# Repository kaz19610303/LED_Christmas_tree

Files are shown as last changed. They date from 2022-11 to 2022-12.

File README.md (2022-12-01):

# LED_Christmas_tree DIY kit



3mm LED 36個と5mm LED1個を使った、LEDクリスマスツリー DIY キットです。  
ご自身でハンダ付けする必要があります。  
  
回路図と基板データを登録していますのでそれを基にオリジナルのクリスマスツリーをお作り下さい。  
現在 Eagle用のデータのみ登録
KiKADデータは準備中 
ドキュメントページはただ今準備中です。

このDIYキットはこちらのページで販売予定です。
https://nextstep.official.ec/  
  
この基板の作成には [JLCPCB](https://jlcpcb.com/HAR) 様の支援を受けています。  
なお現在 JLCPCB は**新規登録で$54クーポン進呈キャンペーン継続中**です。

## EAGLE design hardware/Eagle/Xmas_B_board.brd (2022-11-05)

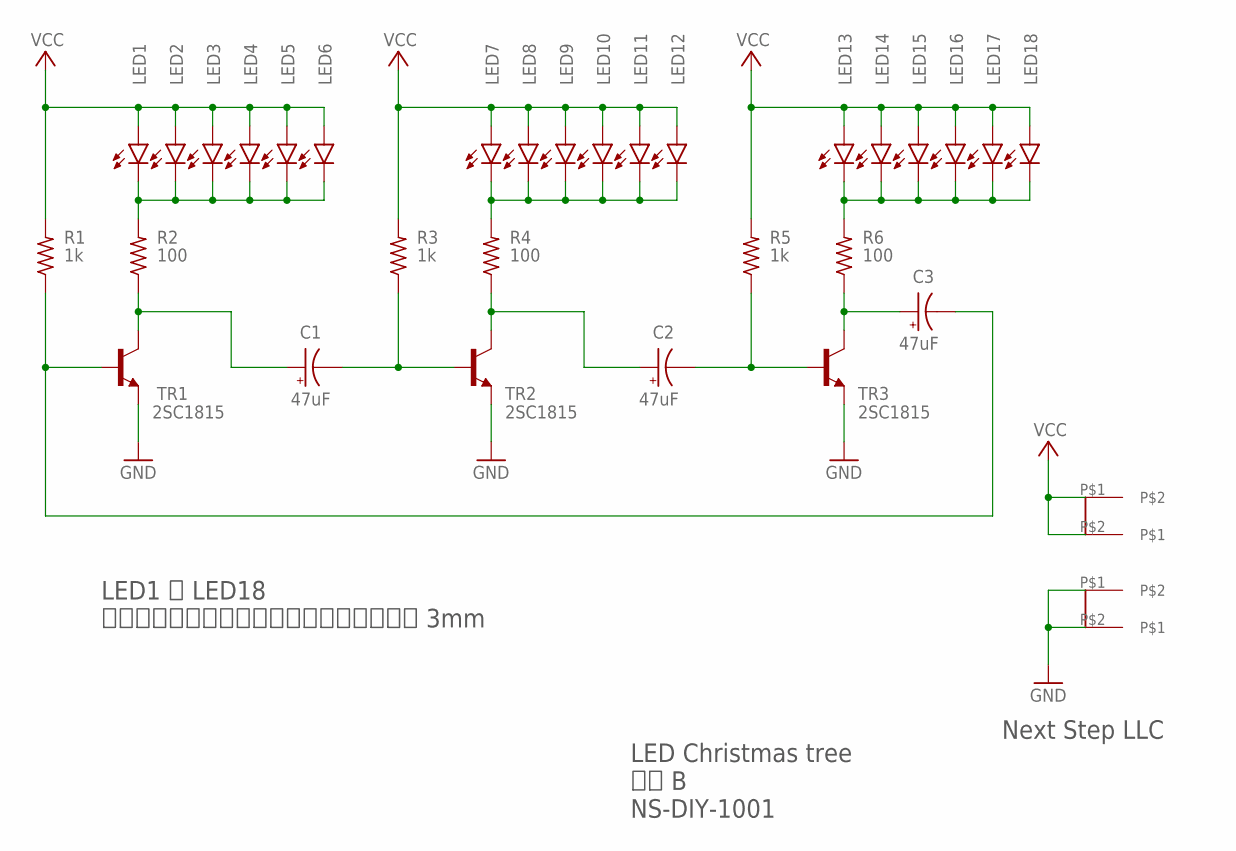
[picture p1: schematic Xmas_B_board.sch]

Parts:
C1, C2, C3: 47uF; E2-4
LED1, LED2, LED3, LED4, LED5, LED6, LED7, LED8, LED9, LED10, LED11, LED12, LED13, LED14, LED15, LED16, LED17, LED18: LED3MM
R1, R3, R5: 1k; 0204/7
R2, R4, R6: 100; 0204/7
TR1, TR2, TR3: 2SC1815; TO92-ECB
U$1, U$2: XMAS_POWER

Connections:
GND: TR1.E, TR2.E, TR3.E, U$2.P$1, U$2.P$2
unnamed: C3.-, R1.1, TR1.B
unnamed: LED1.K (C), LED2.K (C), LED3.K (C), LED4.K (C), LED5.K (C), LED6.K (C), R2.2
unnamed: C1.+, R2.1, TR1.C
unnamed: LED7.K (C), LED8.K (C), LED9.K (C), LED10.K (C), LED11.K (C), LED12.K (C), R4.2
unnamed: C2.+, R4.1, TR2.C
unnamed: C1.-, R3.1, TR2.B
unnamed: C3.+, R6.1, TR3.C
unnamed: C2.-, R5.1, TR3.B
unnamed: LED13.K (C), LED14.K (C), LED15.K (C), LED16.K (C), LED17.K (C), LED18.K (C), R6.2
VCC: LED1.A, LED2.A, LED3.A, LED4.A, LED5.A, LED6.A, LED7.A, LED8.A, LED9.A, LED10.A, LED11.A, LED12.A, LED13.A, LED14.A, LED15.A, LED16.A, LED17.A, LED18.A, R1.2, R3.2, R5.2, U$1.P$1, U$1.P$2

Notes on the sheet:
LED1 ～ LED18 ＲＧＢイルミネーションフルカラーＬＥＤ 3mm
LED Christmas tree 基板 B NS-DIY-1001
Next Step LLC

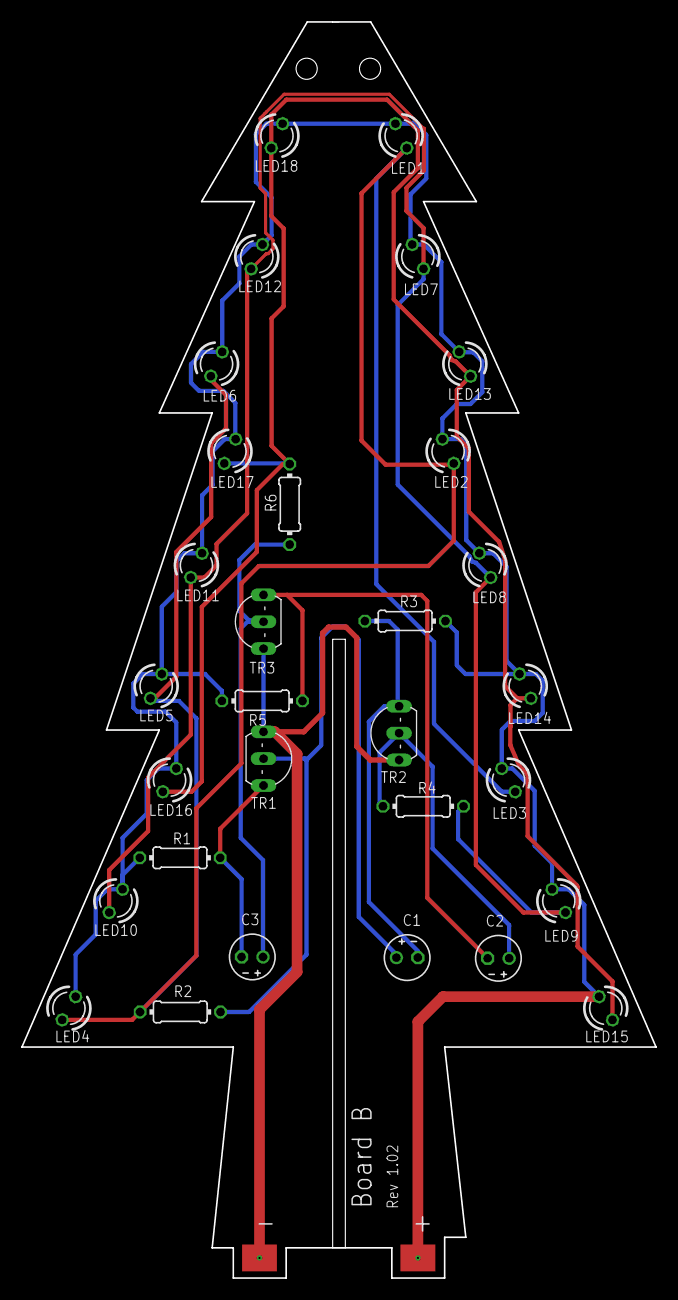
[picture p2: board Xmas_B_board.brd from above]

Board: 2 copper layers, 60.0 x 118.9 mm, 32 parts (0 on the bottom side), 11 nets.

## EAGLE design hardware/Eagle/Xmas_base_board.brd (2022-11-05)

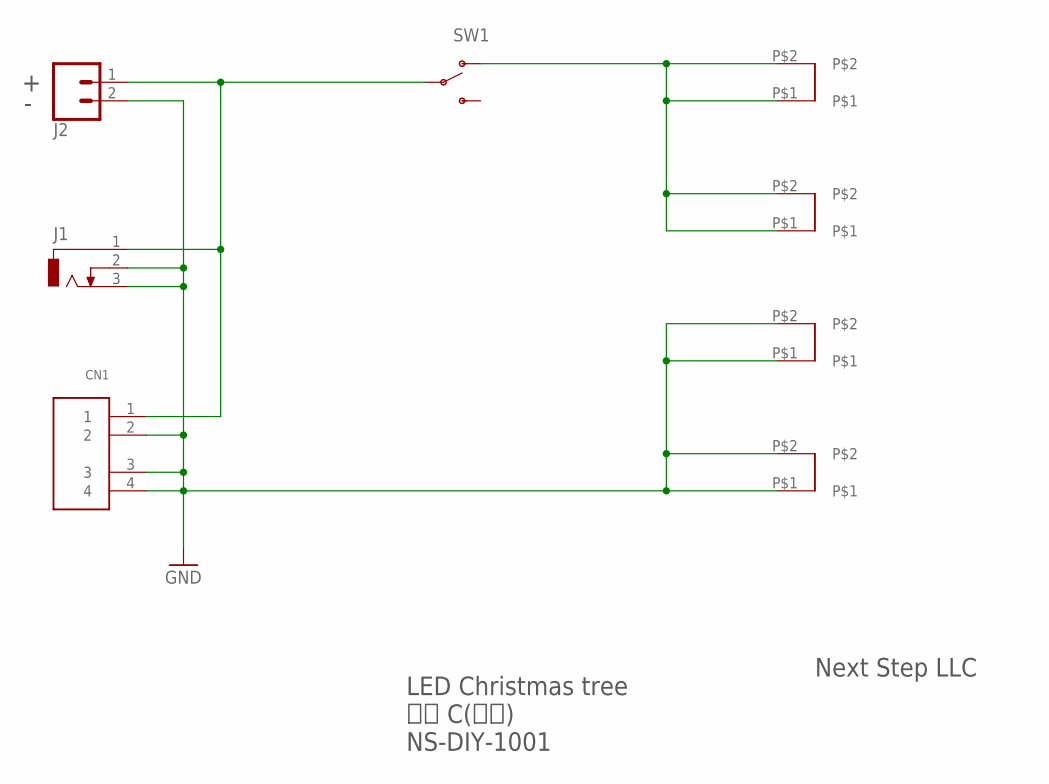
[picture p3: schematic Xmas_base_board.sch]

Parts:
CN1: MRUSB-2B-D14NI-S306_MRUSB-2B
J1: DCJ0303
J2: CONN_02; 1X02
SW1: SWITCH-SPDT-PTH-11.6X4.0MM; SWITCH_SPDT_PTH_11.6X4.0MM
U$5, U$6, U$7, U$8: XMAS-TREE

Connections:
GND: CN1.2, CN1.3, CN1.4, J1.2, J1.3, J2.2, U$7.P$1, U$7.P$2, U$8.P$1, U$8.P$2
unnamed: CN1.1, J1.1, J2.1, SW1.2
unnamed: SW1.1 (O), U$5.P$1, U$5.P$2, U$6.P$1, U$6.P$2

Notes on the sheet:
LED Christmas tree 基板 C(台座) NS-DIY-1001
Next Step LLC

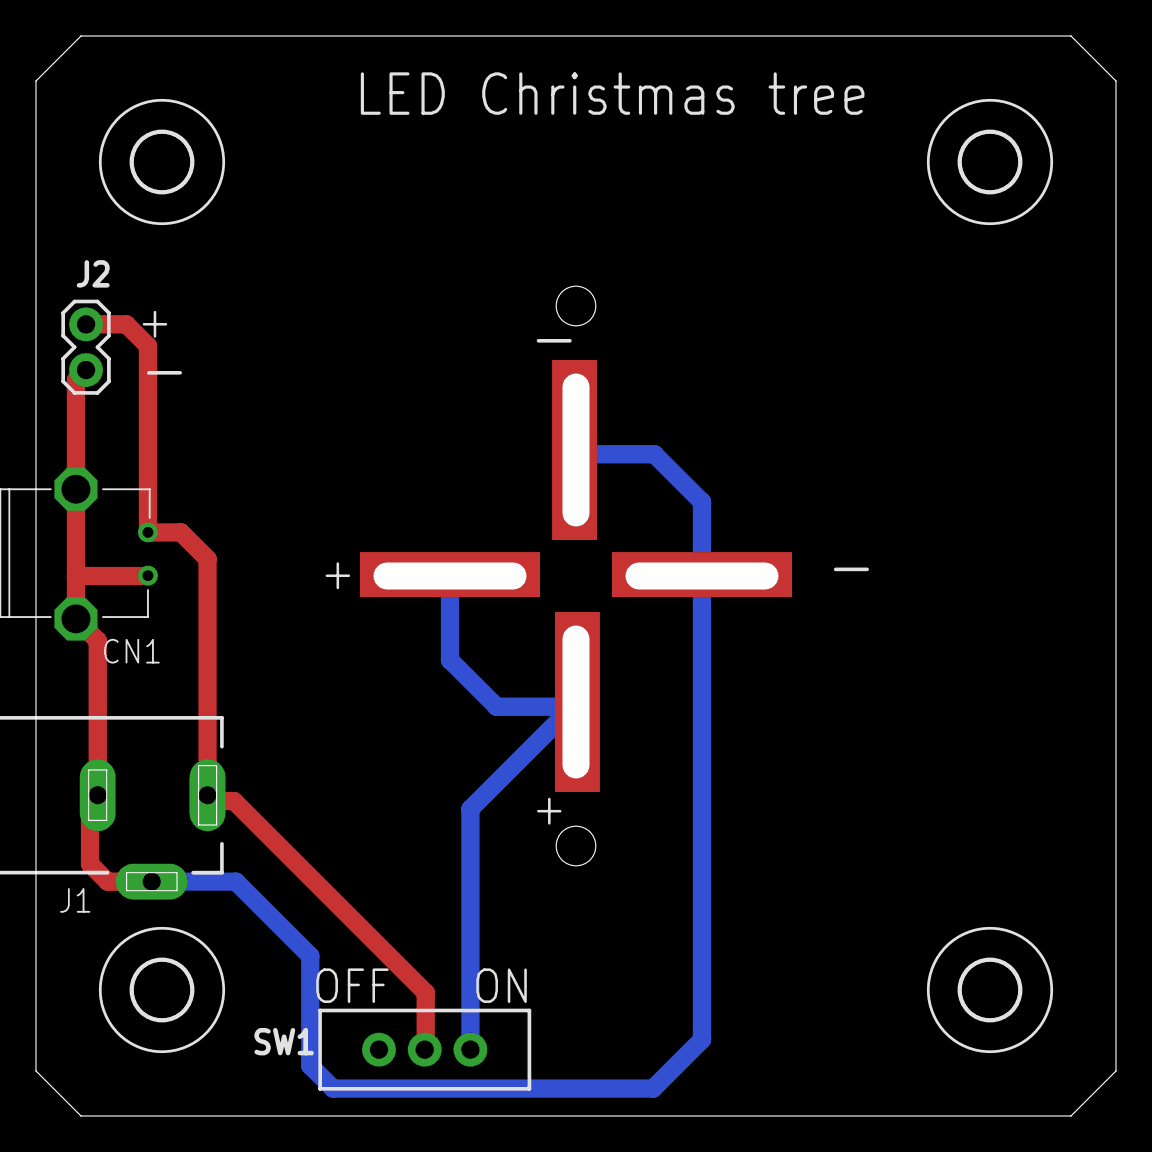
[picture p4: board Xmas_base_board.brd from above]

Board: 2 copper layers, 60.0 x 60.0 mm, 12 parts (0 on the bottom side), 3 nets.

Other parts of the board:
U$1, U$2, U$3, U$4: 3,2

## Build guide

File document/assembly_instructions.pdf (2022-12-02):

# LEDクリスマスツリー組立説明書

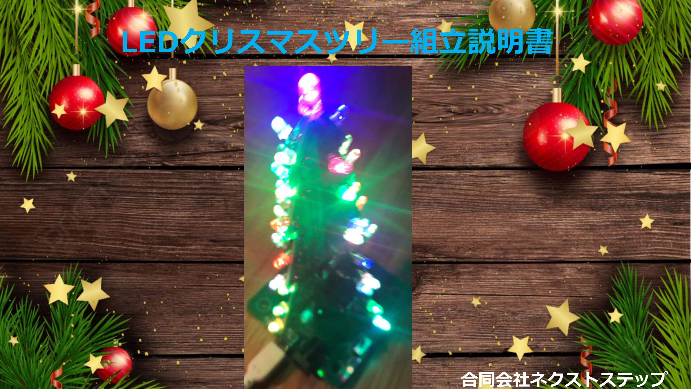
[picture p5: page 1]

# 合同会社ネクストステップ

# 部品表

LEDクリスマスツリー DIY キット A基板 部品表

取付順 | 部品番号 | 品名 | 数量 | 備考
1R2, R4, R6 | | 抵抗 100Ω | 3茶 黒 茶
2R1, R3, R5 | | 抵抗 1kΩ | 3茶 黒 赤
3R7 | | 抵抗 330Ω | 1橙 橙 茶
4LED1 ～ LED18 | | LED 3mm | 18極性あり 足が長い方が ＋
5TR1, TR2, TR3 | | トランジスタ 2SC1815 | 3極性あり 基板の印刷に合わせる、TR2は横に曲げる
6C1, C2, C3 | | 電界コンデンサ 47uF | 3極性あり 足が長い方が ＋
7LED19 | | LED 5mm | 1極性あり 足が長い方が ＋、3枚の基板を組み合わせた後に付ける
| | 基板 | 1

LEDクリスマスツリー DIY キット B基板 部品表

取付順 | 部品番号 | 品名 | 数量 | 備考
1R2, R4, R6 | | 抵抗 100Ω | 3茶 黒 茶
2R1, R3, R5 | | 抵抗 1kΩ | 3茶 黒 赤
3LED1 ～ LED18 | | LED 3mm | 1極性あり 足が長い方が ＋
4TR1, TR2, TR3 | | トランジスタ 2SC1815 | 3極性あり 基板の印刷に合わせる
5C1, C2, C3 | | 電界コンデンサ 47uF | 3極性あり 足が長い方が ＋、そあは下に曲げる
| | 基板 | 1

LEDクリスマスツリー DIY キット ベースボード 部品表

取付順 | 部品番号 | 品名 | 数量 | 備考
1 | | マイクロB | 1
2 | | スライドSW | 1
3 | | DCジャック | 1
| | 基板 | 1
| | 20mmスペーサー | 4
| | 3mmビス | 4

# 組み立てを始める前に 部品が揃っているか確認します

# セット内容

# ① 基板

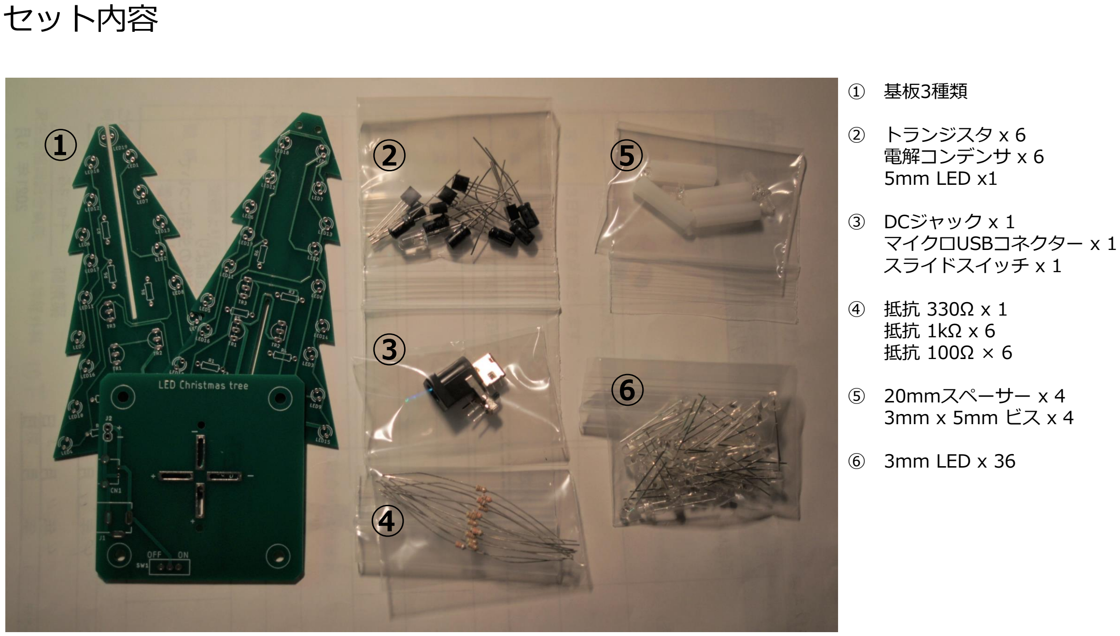
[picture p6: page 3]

3種類

# ② トランジスタ x 6 電解コンデンサ x 6 5mm LED x1

# ③ DCジャック x 1 マイクロUSBコネクター x 1 スライドスイッチ x 1

# ④ 抵抗 330Ω x 1 抵抗 1kΩ x 6 抵抗 100Ω

×

6

# ⑤ 20mmスペーサー x 4 3mm x 5mm ビス x 4

# ⑥ 3mm LED x 36

①

# ②③④

⑤⑥

# A基板回路図

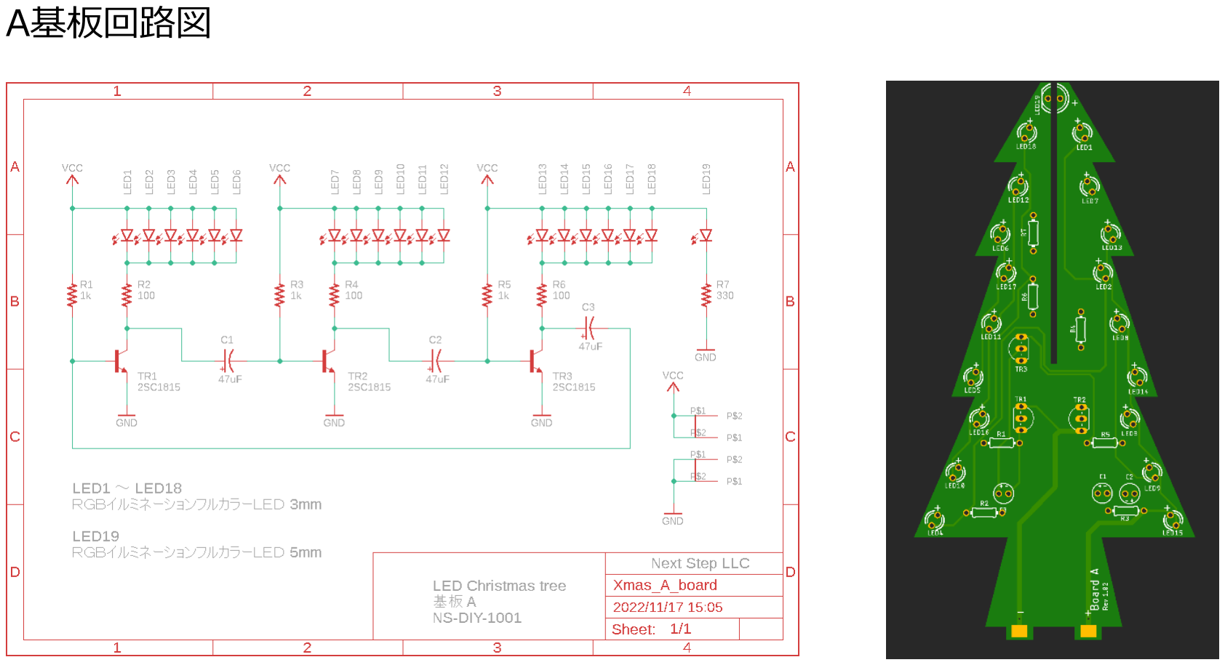
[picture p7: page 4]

# B基板回路図

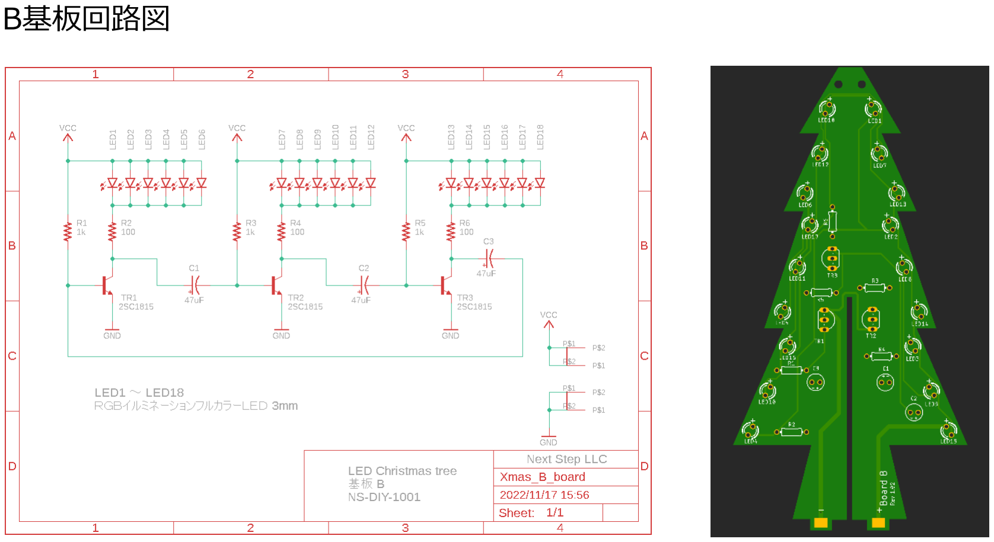
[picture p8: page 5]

# ベース基板回路図

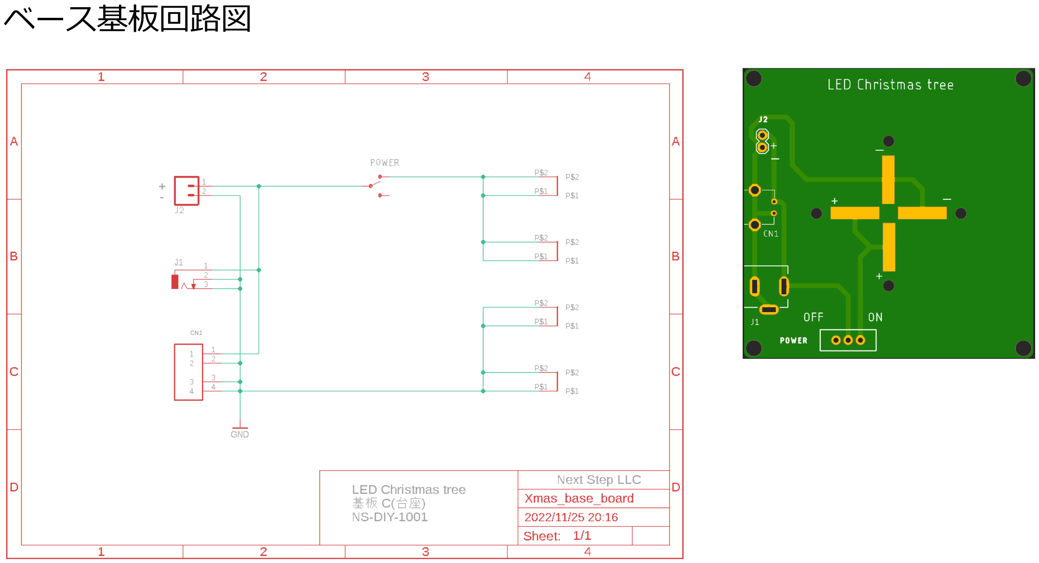
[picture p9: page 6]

# プリント基板

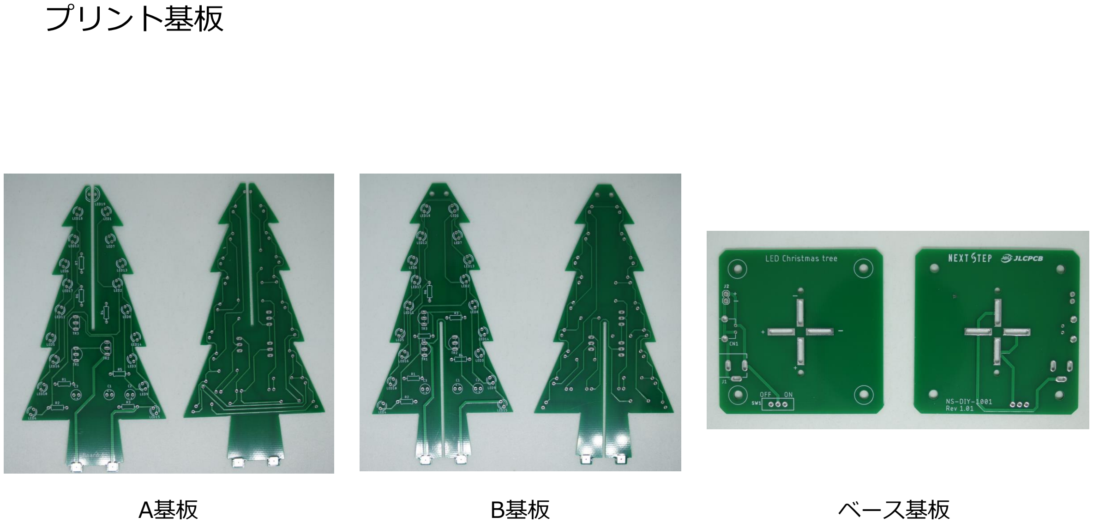
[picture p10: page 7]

A基板 | B基板 | ベース基板

# A基板・B基板の組み立て

① | ② | ③

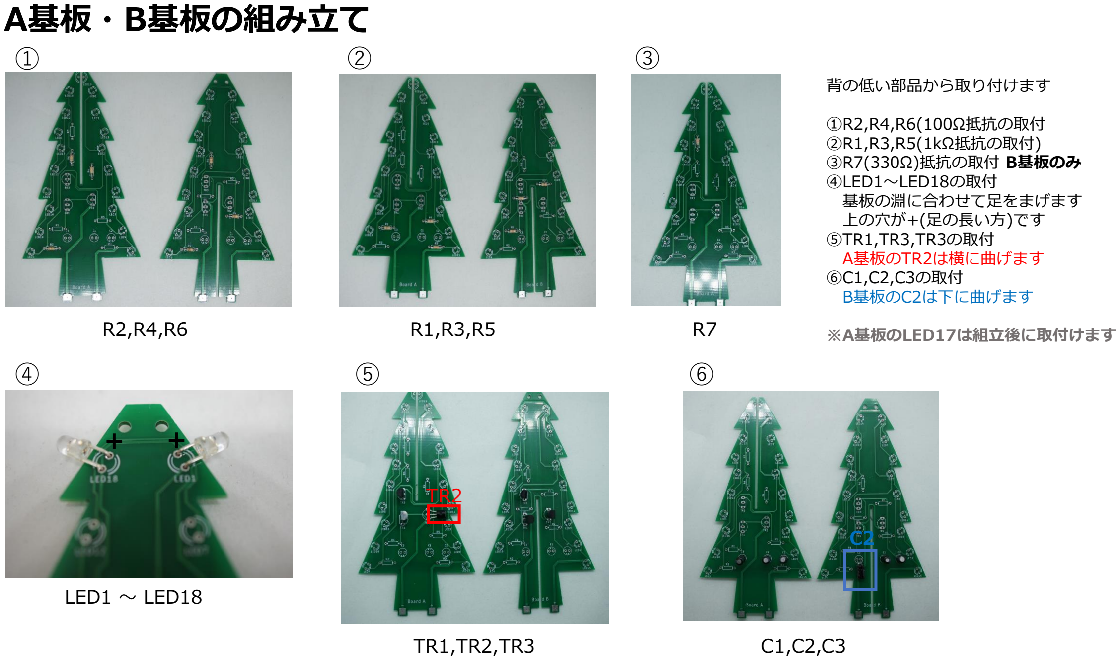
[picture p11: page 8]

R2,R4,R6 | R1,R3,R5 | R7
TR1,TR2,TR3 | C1,C2,C3
④ | ⑤ | ⑥

# LED1 ～ LED18

＋ ＋

# 背の低い部品から取り付けます

# ①R2,R4,R6(100Ω抵抗の取付 ②R1,R3,R5(1kΩ抵抗の取付) ③R7(330Ω)抵抗の取付 B基板のみ ④LED1～LED18の取付 基板の淵に合わせて足をまげます 上の穴が+(足の長い方)です ⑤TR1,TR3,TR3の取付 A基板のTR2は横に曲げます ⑥C1,C2,C3の取付 B基板のC2は下に曲げます

# ※A基板のLED17は組立後に取付けます

TR2

C2

# ベース基板の組み立て

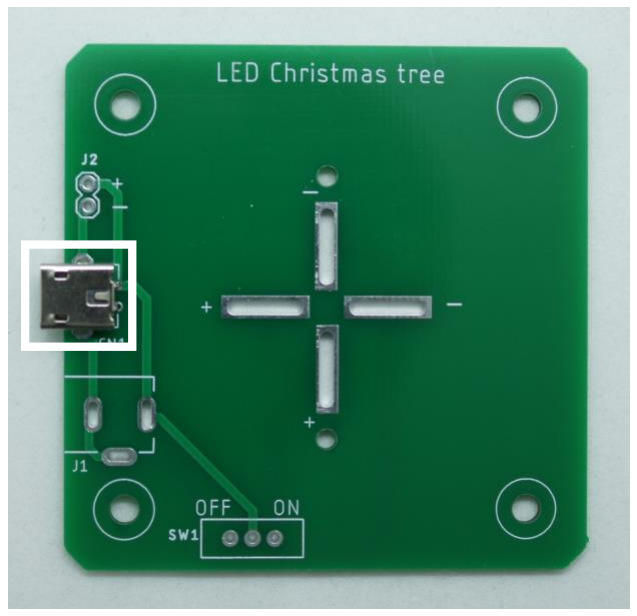
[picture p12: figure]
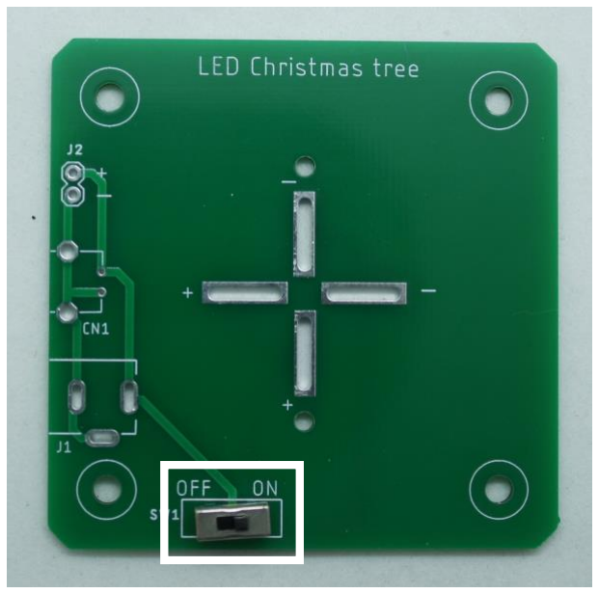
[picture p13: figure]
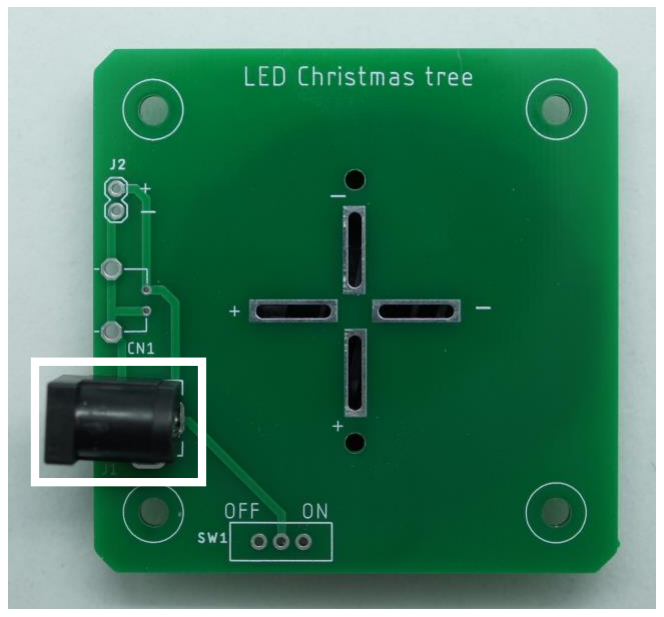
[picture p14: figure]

1. | マイクロUSBコネクター | 2. スライドスイッチ | 3. DCジャック

# ベース基板も背の低い部品からハンダ付けします

# 各基板の組み合わせ

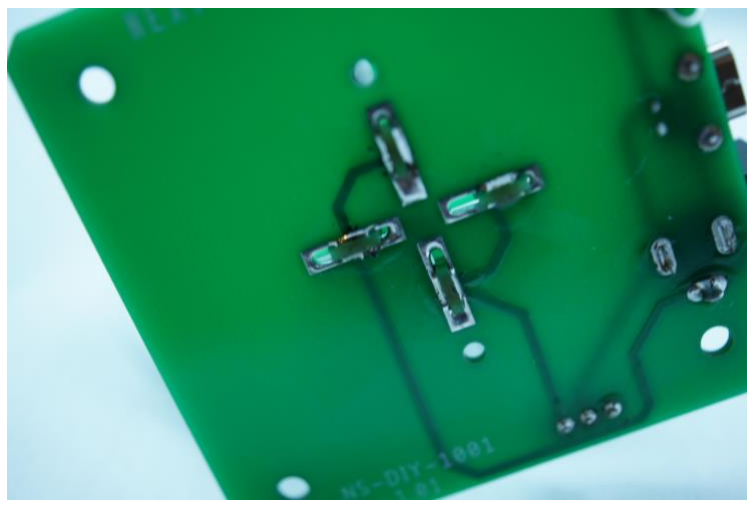
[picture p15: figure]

# A基板・B基板をベース基板にハンダ付けします

# A基板・B基板とベース基板の +と⁻を間違わないようにしてください

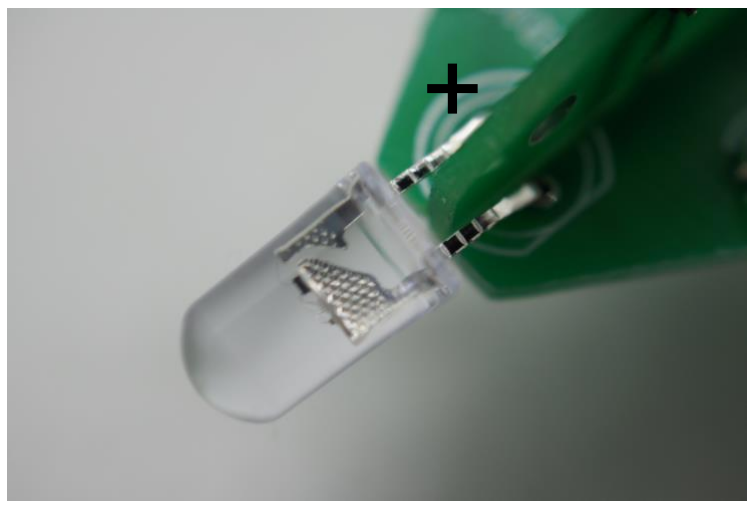
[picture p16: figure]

# LED17の取付

# このLEDも基板の淵に合わせて曲げます 向かって右側が + です

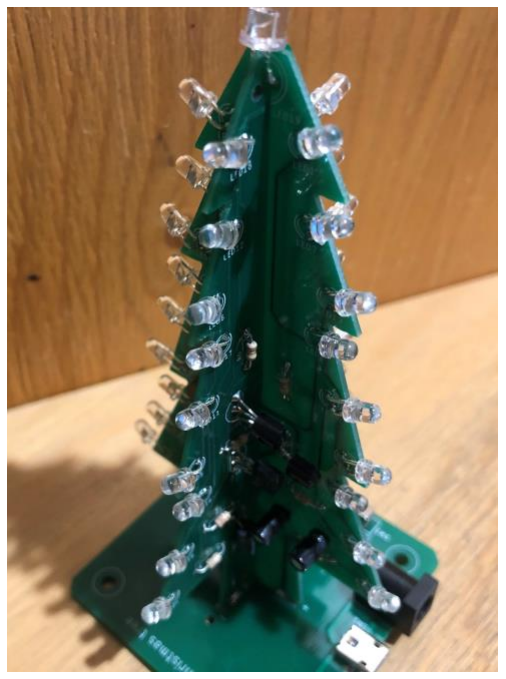
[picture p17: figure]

# A基板・B基板は溝を合わせて組付けます

# 動作確認

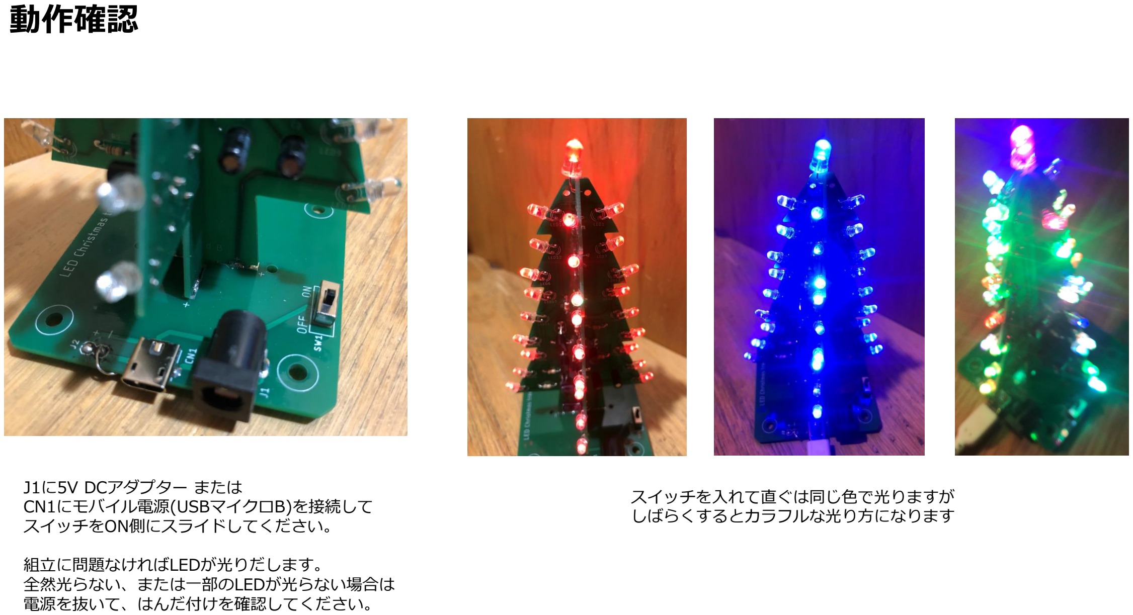
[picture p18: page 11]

# J1に5V DCアダプター または CN1にモバイル電源(USBマイクロB)を接続して スイッチをON側にスライドしてください。

# 組立に問題なければLEDが光りだします。 全然光らない、または一部のLEDが光らない場合は 電源を抜いて、はんだ付けを確認してください。

# スイッチを入れて直ぐは同じ色で光りますが しばらくするとカラフルな光り方になります

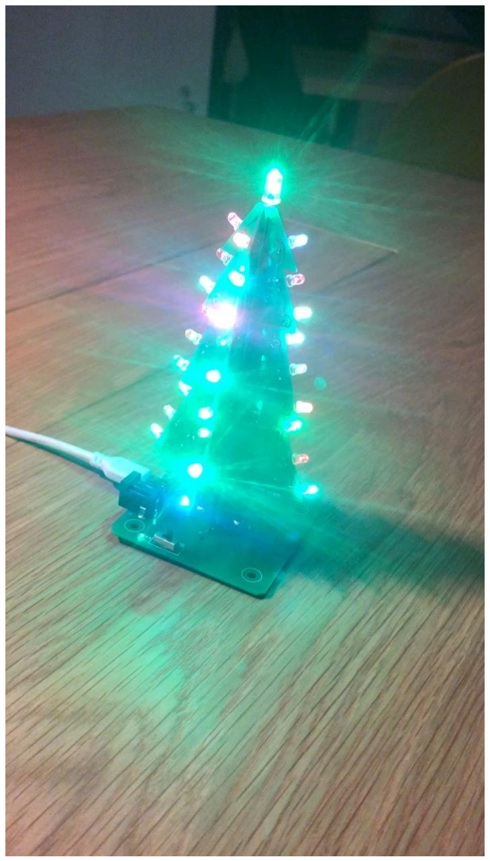
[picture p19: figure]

# 完成したLED クリスマスツリー

# 合同会社 ネクストステップ 問合せ info@next-step.asia

# 販売サイト https://nextstep.official.ec/

# ドキュメントダウンロード GitHUB https://github.com/kaz19610303/LED_Christmas_tree

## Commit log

2022-11-03 Eagle data upload
    [Xmas_A_board.brd, Xmas_A_board.sch, Xmas_B_board.brd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]
2022-11-05 garber data upload
    [Xmas_A_board.brd, Xmas_B_board.brd, Xmas_base_board.brd]
2022-11-05 抵抗の定数変更
    [Xmas_A_board.brd, Xmas_A_board.sch, Xmas_B_board.brd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]
2022-12-01 assembly_instructions 追加
2022-12-01 assembly_instructions upload
2022-12-02 assembly_instructions 加筆

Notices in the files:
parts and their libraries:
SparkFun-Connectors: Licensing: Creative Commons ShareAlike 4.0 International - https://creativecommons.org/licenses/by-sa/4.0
